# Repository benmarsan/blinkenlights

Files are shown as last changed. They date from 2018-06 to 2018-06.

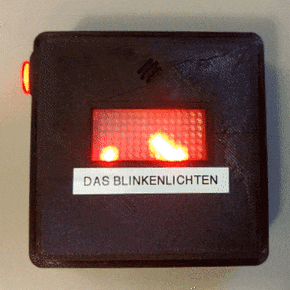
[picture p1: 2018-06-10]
img/animation.gif

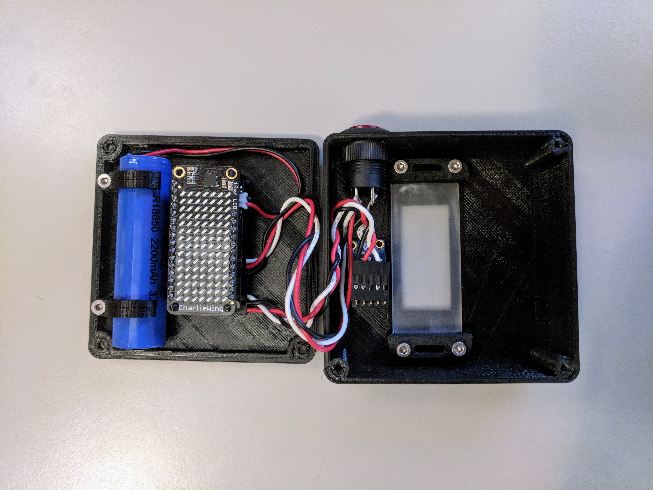
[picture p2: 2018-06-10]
img/inside.jpg

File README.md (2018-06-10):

# Blinkenlights

Uses the Fast Fourier Transform to display frequency spectrum on an LED matrix.
It is powered by an Adafruit Feather M0 which has enough processing power to run
the FFT in real time. All of the electronics fit into a 3d printed case. The
visualized is based on Adafruit's [Piccolo](https://github.com/adafruit/piccolo)
project.

animation

## BOM

### Electronics

| Part | Adafruit Part No. |
|---|---|
| Adafruit Feather M0 Basic | [2772](https://www.adafruit.com/product/2772) |
| Adafruit 15x7 CharliePlex LED Matrix | [3134](https://www.adafruit.com/product/3134) |
| Adafruit Electret Microphone Amplifier | [1713](https://www.adafruit.com/product/1713) or [1063](https://www.adafruit.com/product/1063) |
| 18650 LiPo Battery | [1781](https://www.adafruit.com/product/1781) |
| Latching Illuminated 16 mm Button | [1442](https://www.adafruit.com/product/1442) |

### Hardware

| Item | Qty | McMaster-Carr Part No. |
|---|-----|---|
| M3 x 6 mm Low-Profile Socket-Head Screw | 5 | [92855A307](https://www.mcmaster.com/#92855a307/=1d883ft) |
| M3 x 8 mm Low-Profile Socket-Head Screw | 2 | [92855A309](https://www.mcmaster.com/#92855a309/=1d885do) |
| M3 x 16 mm Low-Profile Socket-Head Screw | 3 | [92855A316](https://www.mcmaster.com/#92855a316/=1d8861v) |
| M2.5 x 6 mm Nylon Screw | 2 | [92492A711](https://www.mcmaster.com/#92492a711/=1d889ul) |
| M2.5 x 8 mm Male-Female Threaded Hex Standoff | 4 | [95783A054](https://www.mcmaster.com/#95783a054/=1d8882d) |
| M2.5 Nylon Hex Nut | 2 | [93800A350](https://www.mcmaster.com/#93800a350/=1d8896z) |
| Male + Female Machine Pin Header 2.54 mm Pitch 1x12 | 1 | - |
| Male + Female Machine Pin Header 2.54 mm Pitch 1x16 | 1 | - |
| Right Angle Pin Header 1x8 | 1 | - |
| Right Angle Pin Header 1x5 | 1 | - |
| Frosted Acrylic, 2-3 x 26 x 60 mm | 1 | - |

## Assembly

### Wiring

The illuminated toggle power button and microphone can be wired to the bottom of
the Feather's proto board with the right angle header and DuPont connectors.

![fritzing](https://lh3.googleusercontent.com/5NHlh4DSRBiCAwgx9jGlC1z4nyOTzJ-hkCKyq0k9myFz3cnMhCXNBUwAQpkvS9XjRSCH_KKlPkHA11y0URVWCTKKEI75pWN2HY5njxVVwcIKkvesRhXAH0ZrfmAbGbTm1EM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)

### 3D Printed Parts

This case was printed at 0.2 mm with supports to prevent chamfered corners from
lifting from the bed. Mic is held into the top with a M3 x 6 mm screw and
washer. The screen holders also use M3 x 6 mm screws. The battery holders use
the two M3 x 8 mm screws, but 6 mm long ones would also work. The Feather is
attached to the bottom with the M2.5 hex standoffs. The two halves are then held
together with the three M3 x 16 mm screws.

![the guts](https://lh3.googleusercontent.com/ncu6nhOK2kZerwsVpyn1Z2fhz47v1G1On_dZgy9rqyUxvE5QJxXIVYwNKmy3qEXZMJ6J6Rewye3NP7yaXyfRT97FbaaLzk3Wtd47Z-DKpQmGL6xmrwgOWhgOHlC3PImebf-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)

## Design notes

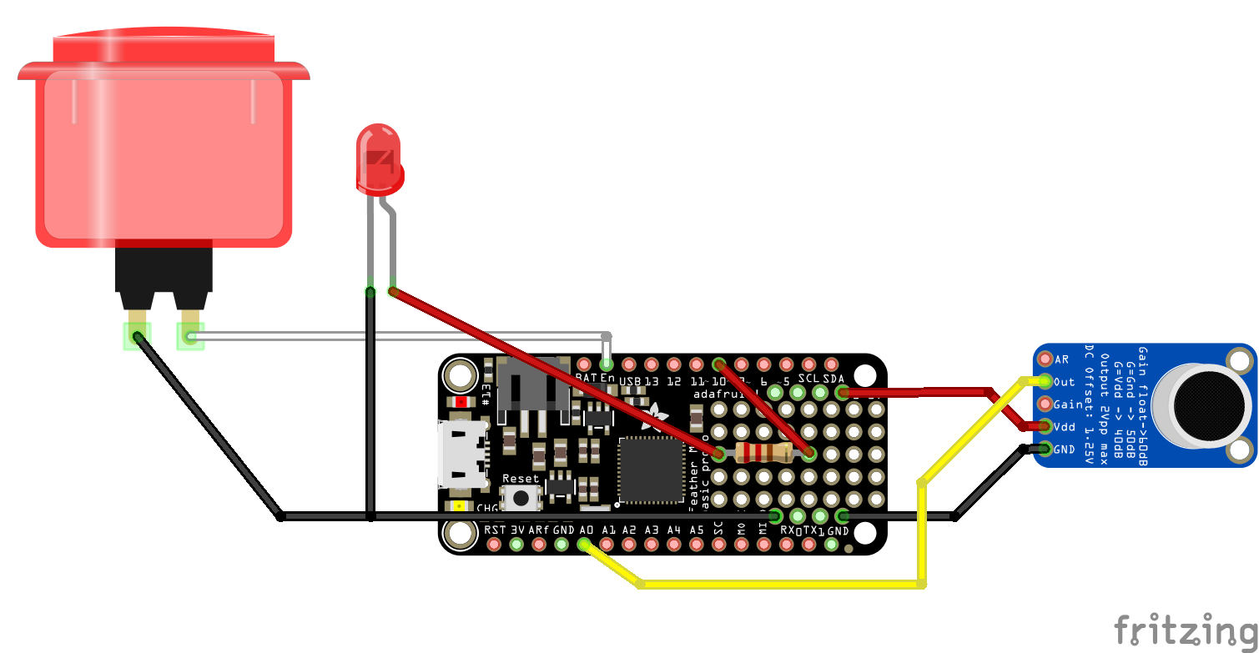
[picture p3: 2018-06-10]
img/fritzing.png

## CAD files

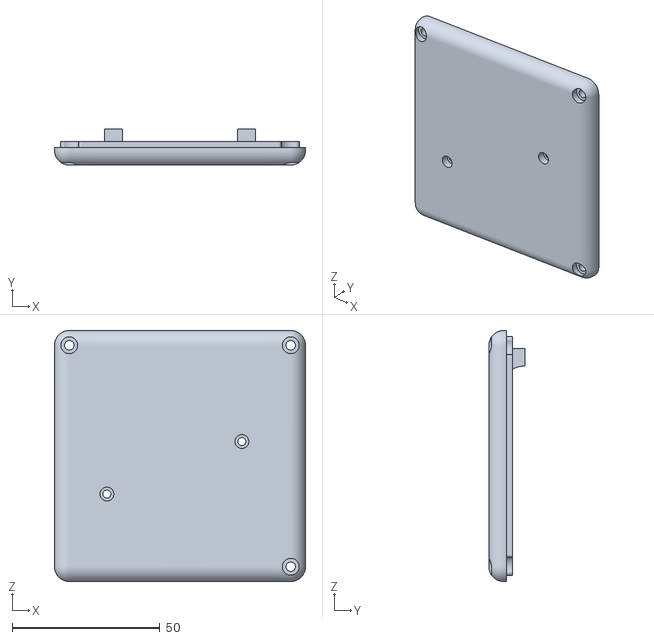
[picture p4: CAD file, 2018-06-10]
cad/Bottom v12.stl
85.0 x 12.3 x 85.0

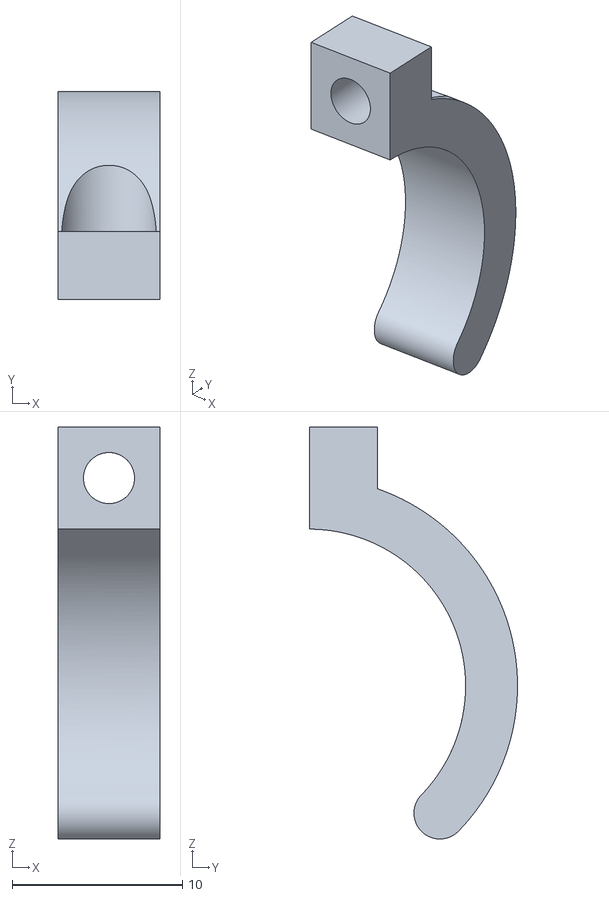
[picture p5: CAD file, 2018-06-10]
cad/Battery Holder v12.stl
6.00 x 12.2 x 24.2

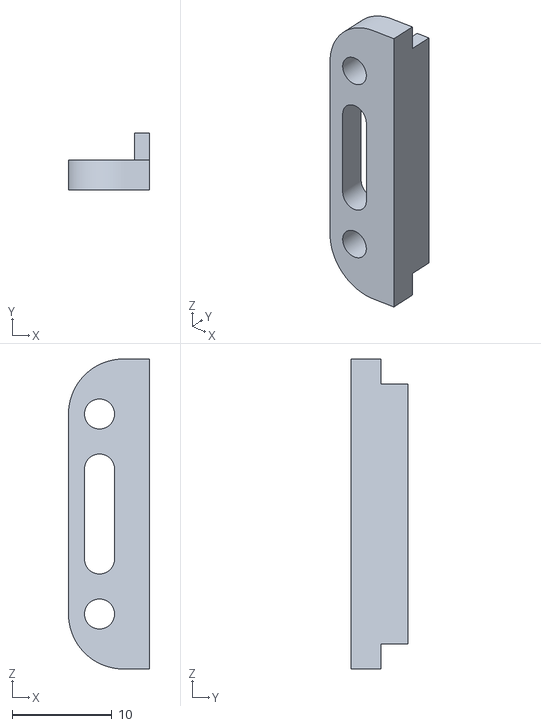
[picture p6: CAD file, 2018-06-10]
cad/Screen Holder v12.stl
8.11 x 5.70 x 31.0

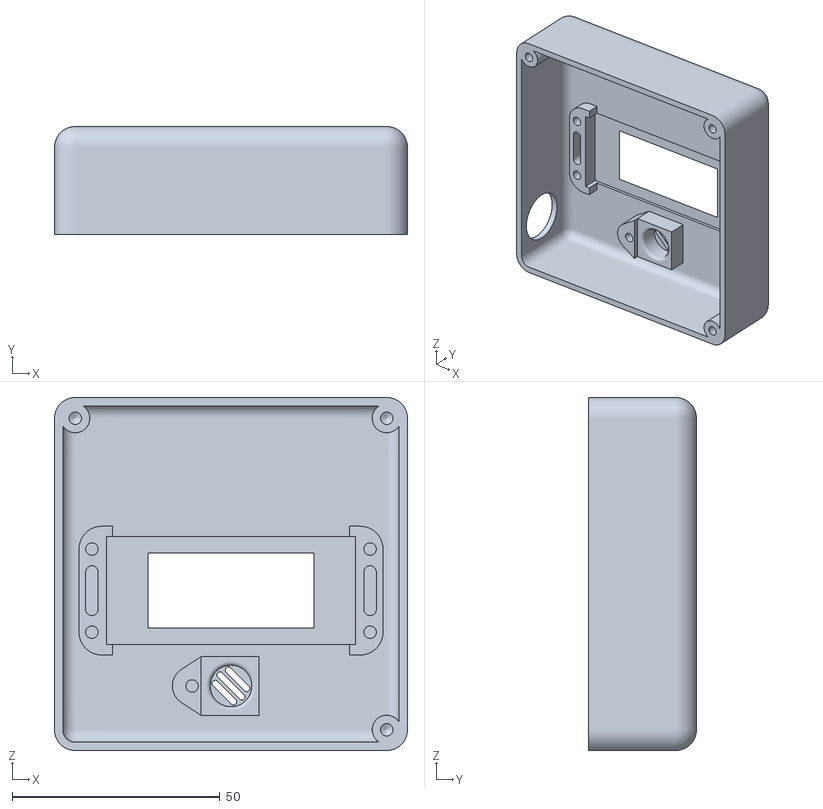
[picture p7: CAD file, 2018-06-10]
cad/Top v12.stl
85.0 x 26.0 x 85.0

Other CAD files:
cad/Case v12.f3d

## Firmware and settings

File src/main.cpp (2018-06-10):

#include <Arduino.h>
#include "Adafruit_ZeroFFT.h"

#include "config.h"
#include "FastADC.h"
#include "DrawFFT.h"

DrawFFT fftDisplay = DrawFFT();

unsigned long microseconds;
int16_t signal[FFT_SIZE];

void setup() {
    // Turn on power button LED
    pinMode(LED_POWER, OUTPUT);
    digitalWrite(LED_POWER, HIGH);

    Serial.begin(115200);

    // Initialize the display object
    if(!fftDisplay.begin()) {
        Serial.println("DrawFFT begin failed");
        while(1);
    }

    // Increase I2C clock speed to maximum of 400000 Hz to speed up display
    // writes.
    Wire.setClock(400000);

    // Setup ADC for fast reads
    selAnalog(MIC_PIN);
    fastADCsetup();
}

void loop() {
    for(int i = 0; i < FFT_SIZE; i++) {
        microseconds = micros(); // Overflows after around 70 minutes!

        // Read mic into signal[i]
        signal[i] = anaRead() - MIC_DC_OFFSET;

        // Delay for sampling_period_us to read at SAMPLE_RATE
        while(micros() < (microseconds + sampling_period_us));
    }

    // Compute FFT
    ZeroFFT(signal, FFT_SIZE);

    // Draw to matrix
    fftDisplay.update(signal);
}

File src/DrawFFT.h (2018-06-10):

#include <Arduino.h>
#include <Adafruit_GFX.h>
#include <Adafruit_IS31FL3731.h>

#ifndef DRAW_FFT_H
#define DRAW_FFT_H

class DrawFFT
{
  private:
    Adafruit_IS31FL3731_Wing matrix;

    uint8_t peak[15] = {},      // Peak level of each column for falling dots
        dotCount = 0,           // Frame counter for delaying falling dots
        colCount = 0,           // Frame counter for storing past column data
        drawFrame = 1;          // Frame counter for double bufferred drawing

    uint8_t LED_OFF = 0,
            LED_LOW = 8,
            LED_MID = 16,
            LED_HIGH = 64,
            LED_ON = 255;

    uint8_t col[15][10];        // Column levels for past 10 frames
    int16_t minLvlAvg[15] = {}; // Dynamic adjustment of high and low
    int16_t maxLvlAvg[15] = {}; //   levels of graph (probably only sets first item?)
    int16_t colDiv[15] = {};    // Used to filter FFT to 15 columns

    // Noise constants to subtract from FFT output
    static constexpr int16_t noise[32] = {
            190, 105, 8, 8, 5, 5, 5, 5,     // 0-7
            5, 5, 5, 5, 5, 5, 5, 5,         // 8-15
            3, 3, 3, 2, 2, 2, 2, 2,         // 16-23
            2, 2, 2, 2, 2, 2, 2, 2          // 24-32
        };

    // FFT outputs are multiplied by EQ constants to change weight of certain
    // bins.
    static constexpr float eq[32] = {
            1, 1, 1, 1, 1, 1, 1, 1,         // 0-7
            1, 1, 1, 1, 1, 1, 1, 1,         // 8-15
            1, 1, 1, 1, 1, 1, 1, 1,         // 16-23
            1, 1, 1, 1, 1, 1, 1, 1,         // 24-32
        };

  public:
    DrawFFT();
    int begin();
    void update(int16_t *spectrum);
};

#endif

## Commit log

2018-06-03 Switch to ADC for mic input
2018-06-04 Embed charlieplex library to increase I2C clock
2018-06-04 Add error handling to DrawFFT::begin
    [DrawFFT.h, main.cpp]
2018-06-07 Clean up DrawFFT, add noise subtraction
    [DrawFFT.h]
2018-06-10 Clean up headers, moved i2c clock to main
2018-06-10 Add comment on I2C clock speed
2018-06-10 Update README.md Add BOM and images
2018-06-10 Update README.md Add right angle pin header
2018-06-10 Add 3d files
    [Battery Holder v12.stl, Bottom v12.stl, Case v12.f3d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]
